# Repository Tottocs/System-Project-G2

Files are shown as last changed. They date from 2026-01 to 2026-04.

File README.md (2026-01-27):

# Description

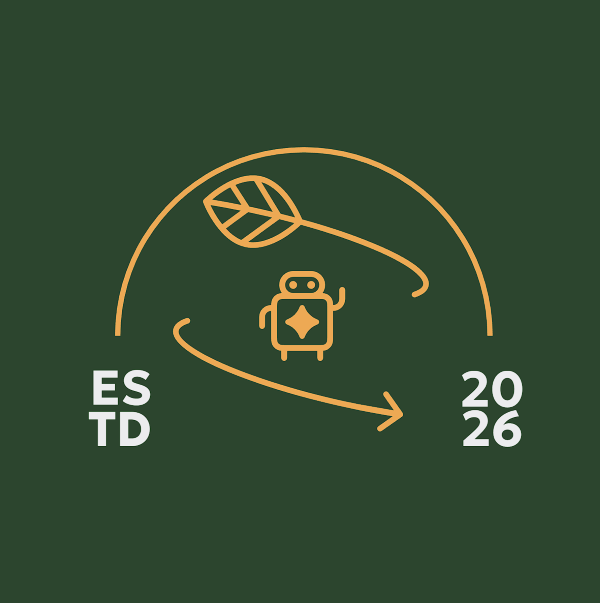
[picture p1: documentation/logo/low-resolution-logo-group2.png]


Recycling robot that collects rubbish and places it in designated areas.  
Includes code and CAD models with documentation.

## The Team

> - Abdalrahman Al-Zandi
>>Managing Director  
>>Mechanical Engineer
> - Torin Stanton-Andersson
>>Digital Systems Engineer  
>>Electronic and Wiring Engineer
> - David Mariani
>>Workshop Engineer  
>>Electronics and Wiring Engineer  
> - Aidan Johnstone
>>Software Engineer  
>>Personal Relations  
> - Lucy Grierson
>>Company Secretary  
>>Software Engineer  
> - Ben Albeson
>>Web Designer  
>>Digital Systems Engineer  

## Naming Convention For Files  

Lowercase and hyphen with group2 at end:  
***name-name-group2.c*** // Example of c file

Exception is when document is not created by the team.  
Then group2 is not used.

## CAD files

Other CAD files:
mechanical/base-group2.iam
mechanical/base/buggy-body-assembly-ready-group2.ipt
mechanical/base/rubbish-container-group2.ipt
mechanical/base/us-sensor-mount.ipt
mechanical/battery-model-group2.ipt
mechanical/buggy-body-group2.ipt
mechanical/buggy-group2.iam
mechanical/buggy/battery-model-two-group2.ipt
mechanical/buggy/buggy-topside-group2.ipt
mechanical/buggy/line-follower-group2.ipt
mechanical/buggy/motor-group2.ipt
mechanical/buggy/nub-group2.ipt
mechanical/buggy/nut-group2.ipt
mechanical/buggy/wheel-group2.ipt
mechanical/crane-base-assembly.iam
mechanical/crane/horozontal-arm-comp-group2.ipt
mechanical/crane/rotating-base-bottom-group2.ipt
mechanical/crane/rotating-base-head-group2.ipt
mechanical/crane/spool-group2.ipt
mechanical/door-assembly-group2.iam
mechanical/door/door-group2.ipt
mechanical/door/door-pinion-group2.ipt
mechanical/door/door-rail-group2.ipt
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

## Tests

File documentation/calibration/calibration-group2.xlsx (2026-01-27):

100 | 1 | 2 | 3 | Init left spd | Total |  |  | Testing straight
Min Blinks | 8 | 10 | 10 | 80 | 126.6666667 | 126.6666667% |  | First two sec | After
Max Blinks | 10 | 11 | 11 | 80 | 133.3333333 | 133.3333333% | 126 vs 100 | right | straight
 |  |  |  |  |  |  | 190 vs 150 | right | straight
150 | 1 | 2 | 3 | Init left spd | Total | Percent | 233 vs 200 | slight right | slight left
Min Blinks | 13 | 13 | 13 | 130 | 190 | 126.6666667%
Max Blinks | 14 | 15 | 15 | 130 | 203.3333333 | 135.5555556% | Battery at 3 bars
200 | 1 | 2 | 3 | Init left spd | Total
Min Blinks | 14 | 14 | 13 | 170 | 233.3333333 | 116.6666667%
Max Blinks | 15 | 15 | 15 | 170 | 245 | 122.5%

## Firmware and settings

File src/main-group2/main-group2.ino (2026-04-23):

#ifndef FIRMWARE_VERSION
#define FIRMWARE_VERSION "v.0.6" //Implementation of line following
#endif

/*
Authors: Lucy Grierson, Torin Stanton-Andersson, Ben Albeson

[] Ultrasonic Sensor
[x] RGB Sensor
[x] Motors
[x] Servos (Which ones)
[x] IR sensors
[x] Status LEDs
[x] Buzzer

Optional:
[] Eyes

*/


//Including project libraries
#include "include/ultrasonic-sensor-group2.h"
#include "include/ir-sensor-group2.h"
#include "include/motor-group2.h"
#include "include/rgb-sensor-group2.h"
#include "include/door-group2.h"

//Including online libraries
#include <Servo.h>

//UART only needed for debugging and or comunication between chips. Will slow the arduino computation
#define SERIAL_STATUS true // set false for field operation
#define UART_BAUDRATE 9600 //might need to be changed

// PINS
//---------------------------------
//Servo pins
#define DOOR_PIN 9

//Motor pins
#define MOT_A1_PIN 5 // IN2
#define MOT_A2_PIN 6 // IN1
#define MOT_B1_PIN 11 // IN3
#define MOT_B2_PIN 3 // IN4
#define CR_STATE_PIN 12
#define BUZZ_PIN 3
#define MAGNET_PIN A2
//Peripheral 
#define BUTTON 7

//Debug LEDs
#define ERROR_LED 4
#define CALIBRATION_LED 8
#define RUNNING_LED 13

int IR_Sensor_Pins[3] = {A3,A2,A1};
int positions[4] = {20, 80, 130, 170};// [0]=pickup, [1-3]=bins
#define CRANE_SERVO_PIN 10 // change to free pin

// CONSTANTS
//------------------------------------
#define MAGNET_ON 1023
#define MAGNET_OFF 0
//MAX and MIN distances for detectable object (cm)
#define MIN_DIST 1 //Needs to be changed
#define MAX_DIST 20 //Needs to be changed

//Number of rubiish objects to pick up
#define N_OBJECTS 3

#define DOOR_OPEN_STATE 1
#define DOOR_CLOSED_STATE 0

//Delays in ms
#define START_DELAY 1000
#define DRV_OFF_BLK_DEL 500
#define BASE_DELAY 700
#define DROPOFF_DELAY 1500
#define OBSTACLE_DELAY 2000
#define BLK_CONFIRM_DELAY 50
#define TURN_DELAY 700
#define CRANE_MOVE_DELAY 1000
#define MAGNET_MOVE_DELAY 1000

//Timout
#define BLK_LINE_TIMEOUT 500UL 
#define BLINK_LENGTH 500

//Buzzer
#define BUZZ_FREQ 3000
#define BUZZ_DURATION 500
#define BEEP_PAUSE_TIME 300
#define NUM_BEEPS 2

//Refresh rate of entire programme in ms
#define REFRESH_RATE 50

//Speeds
#define NOMINAL_SPD 120
#define STARTING_SPD 80
#define DROPOFF_SPD 80
#define OBSTACLE_SPD 80
#define LINE_CAL_SPD 100
#define TURN_SPD 100
#define HOME_SPD 80
 
//Distances in cm
#define DIST_TO_DROPOFF 5

//Line following
#define ALL_BLACK B111
#define NO_BLACK B000

#define LM_CORRECTION 100 // Left motor correction

// OBJECTS
// --------------------------------------
Servo door;
Servo CraneServo;

RgbSensor rgbSensor;

// VARIABLES
//---------------------------------------

//90 degree turn checker
bool turned90 = false;

//130 degree turn checker
bool tunred130 = false;

//180 degree turn checker
bool turned180 = false;

//Motor speed variables
int LeftMotorSpeed = 0;
int RightMotorSpeed = 0;

//US sensor variables
unsigned long DistanceFront; //front sensor 
unsigned long DistanceRight; //side sensor
unsigned long DistanceBack; //back sensor

//IR Sensor variable
volatile int IR_Sensor_Status = B000;

//pickup and dropoff
int pickup = 0;
int dropoff = 0;

//
int visitedBins = 0;

//state 3
int dropOff = 0;

int ObjectDetected = 0;

char ObjectColour = 0;

char GetBinFromColor() { 
  ObjectColour = rgbSensor.detectDominantColor();
  const char R = 1;
  const char G = 2;
  const char B = 3;
  switch(ObjectColour) {
    case R:   return 1; // bin 1
    case G:   return 2; // bin 2
    case B:   return 3; // bin 3
    default:    return 1; // default bin (safe fallback)
  }
}

//states
enum RobotState {
  ERROR = 0,
  STARTING = 1,
  FOLLOW_LINE = 2,
  DROPOFF = 3,
  PICKUP = 4,
  HOME = 5,
  OBSTACLE = 6,
  FINISHED = 7
};

RobotState CurrentState = STARTING;

int startStage = 0;
int obstacleStage = 0;
int HomeState = 1;
bool HomeTurned = false;


void setup() {
  //setup serial
  #if SERIAL_STATUS == true 
  Serial.begin(UART_BAUDRATE); //Only used for debugging
  #endif
  //Button for calibration
  pinMode(BUTTON, INPUT_PULLUP);

  //Debug LEDs
  pinMode(ERROR_LED, OUTPUT);
  pinMode(CALIBRATION_LED, OUTPUT);
  pinMode(RUNNING_LED, OUTPUT);
  digitalWrite(RUNNING_LED, HIGH);
  
  //Servo setup
  door.attach(DOOR_PIN);
  CraneServo.attach(CRANE_SERVO_PIN);
  moveToPosition(0); // default pos

  //Crane
  pinMode(CR_STATE_PIN, OUTPUT);
   
  //Setup up ir sensor pins
  if (!Setup_IR_Sensors(IR_Sensor_Pins, BUTTON, CALIBRATION_LED)) {
    CurrentState = ERROR;
  } 
  digitalWrite(CALIBRATION_LED, LOW);

  //Setup main motor pins
  Setup_Main_Motors(MOT_A1_PIN, MOT_A2_PIN, 
                    MOT_B1_PIN, MOT_B2_PIN);

  //Setup rgb sensor
  rgbSensor.begin();
  //Set_Motor_Currents(NOMINAL_SPD, NOMINAL_SPD);
  //delay(3000); 


}

void loop() {
  //Serial.println(CurrentState);

  
  if (CurrentState != ERROR) { // Testing
     //CurrentState = STARTING;  
  }
  
  IR_Sensor_Status = Scan();
  switch(CurrentState)
  {

    case STARTING:
      Starting();   break;

    case FOLLOW_LINE:
      FollowLine(); break;

    case DROPOFF:
      Dropoff();    break;

    case PICKUP:
      Pickup();     break;

    case HOME:
      Home();       break;

    case OBSTACLE:
      Obstacle();   break;

    case ERROR:
      Error();      break;

    default:
      CurrentState = ERROR;
  }
  //delay(REFRESH_RATE); //might get rid
  
}

// State functions
// -------------------------------------------------

//STATE 1 go from charging point to line  
void Starting()
{
  switch(startStage)
  {
    // STEP 0
    case 0:
      Set_Motor_Currents(STARTING_SPD,STARTING_SPD);
      delay(BASE_DELAY);
      startStage = 1;
      break;
    case 1:

      Update_Direction(&LeftMotorSpeed,&RightMotorSpeed);
      Set_Motor_Currents(LeftMotorSpeed,RightMotorSpeed);
      if(IR_Sensor_Status == B111)
      { 
        Set_Motor_Currents(STARTING_SPD,STARTING_SPD);
        delay(BASE_DELAY);
        startStage = 2;
      }
      break;

    // STEP 2 turn right 
     case 2:
      Set_Motor_Currents(0,0);
      Turn_90_Clockwise();
      startStage = 0;
      CurrentState = FOLLOW_LINE;
      break;
    
    default:
      CurrentState = ERROR;
  }
}


//STATE 2 line following and pickup
void FollowLine()
{
  if(DistanceFront > MIN_DIST && DistanceFront < MAX_DIST)
  {
    CurrentState = OBSTACLE;
    return;
  }

  Update_Direction(&LeftMotorSpeed,&RightMotorSpeed);
  Set_Motor_Currents(LeftMotorSpeed,RightMotorSpeed);
  if (IR_Sensor_Status == ALL_BLACK) {
    Set_Motor_Currents(0,0);
    delay(BLK_CONFIRM_DELAY);
    Calibrate_On_Line(BLK_LINE_TIMEOUT);
  }

  if(ObjectDetected)
  {
    //PickupObject();
    //pickup code here or call helper ^
    pickup++;
  }

  if(pickup >= N_OBJECTS)
  {
    CurrentState = DROPOFF;
  }

}


//STATE 3 drop off 

void Dropoff()
{
  dropoff = 0;
  switch(dropoff)
  {
    // Detect drop-off area and move slightly forward
    case 0:
      if((IR_Sensor_Status == ALL_BLACK) && 
         (DistanceRight > MIN_DIST && DistanceRight < MAX_DIST))
      {
        Set_Motor_Currents(DROPOFF_SPD, DROPOFF_SPD);
        delay(DROPOFF_DELAY);

        Set_Motor_Currents(0, 0);
        dropoff = 1;
      }
      break;

    // Turn so the back faces the bin
    case 1:
      Turn_90_Anti_Clockwise();
      dropoff = 2;
      break;

    // Reverse until rear sensor detects bin
    case 2:
      Set_Motor_Currents(-NOMINAL_SPD, -NOMINAL_SPD);

      if (DistanceBack <= DIST_TO_DROPOFF)  // bin detected
      {
        Set_Motor_Currents(0, 0);
        dropoff = 3;

      }
      break;

    // Drop objects
    case 3:
      setDropoff(door, DOOR_OPEN_STATE);   // OPEN DOOR
      delay(500);      // allow servo to move
      dropoff = 4;
      break;

    // Move forward away from bin
    case 4:
      Set_Motor_Currents(NOMINAL_SPD, NOMINAL_SPD);
      delay(300);
      dropoff = 5;
      break;

    // Close door + return to line following
    case 5:
      setDropoff(door, DOOR_CLOSED_STATE);   // CLOSE DOOR

      Update_Direction(&LeftMotorSpeed, &RightMotorSpeed);
      Set_Motor_Currents(LeftMotorSpeed, RightMotorSpeed);

      if(IR_Sensor_Status != NO_BLACK)
      {
        dropoff = 0;
        CurrentState = FOLLOW_LINE;
      }
      break;
  }
}

void Pickup() {

  Set_Motor_Currents(0,0); // stop robot

  //go to pickup position
  moveToPosition(0);
  delay(CRANE_MOVE_DELAY);
  
  //input detect colour
  
  digitalWrite(CR_STATE_PIN, HIGH);//lower magnet
  delay(MAGNET_MOVE_DELAY);

  //activate electromagnet
  analogWrite(MAGNET_PIN, MAGNET_ON);
  delay(500);

  //lift object
  digitalWrite(CR_STATE_PIN, LOW);
  delay(MAGNET_MOVE_DELAY);

  //choose bin
  char binIndex = GetBinFromColor();

  //rotate to bin
  moveToPosition(binIndex);
  delay(800);

  //release object
  analogWrite(MAGNET_PIN, MAGNET_OFF);
  delay(500);

  //return to pickup position
  moveToPosition(0);

  pickup++;
  ObjectDetected = 0;

  CurrentState = FOLLOW_LINE;


}

//STATE 4 go home
void Home()
{
  const int Follow_Line = 1;
  const int Turning = 2;
  const int End = 3;
  
  //HomeState = End;
  switch (HomeState) {
  
  case Follow_Line:
    Update_Direction(&LeftMotorSpeed, &RightMotorSpeed);
    Set_Motor_Currents(LeftMotorSpeed, RightMotorSpeed);
    //if buggy has reached line turn onto line and stop at base line
    if(IR_Sensor_Status == ALL_BLACK)
    {
      Set_Motor_Currents(0,0);
      delay(BLK_CONFIRM_DELAY);
      Calibrate_On_Line(BLK_LINE_TIMEOUT);
      Set_Motor_Currents(NOMINAL_SPD*LM_CORRECTION/100,NOMINAL_SPD);
      delay(TURN_DELAY);
      HomeState = Turning;
    }
    break;
  
  case Turning:
    //Turn right
    Set_Motor_Currents(TURN_SPD*LM_CORRECTION/100,-TURN_SPD);
    if (IR_Sensor_Status == B001) {
      HomeState = Follow_Line;
      if (HomeTurned) {
        Set_Motor_Currents(TURN_SPD*LM_CORRECTION/100,-TURN_SPD);
        if (IR_Sensor_Status == B001) {
          HomeState = End;
        }
      }
      HomeTurned = true;
    }
    break;

  case End:
    Update_Direction(&LeftMotorSpeed, &RightMotorSpeed);
    Set_Motor_Currents(-RightMotorSpeed, -LeftMotorSpeed);
    if (IR_Sensor_Status == ALL_BLACK) {
      Set_Motor_Currents(0,0);
      exit(0); // stop forever until reset or power cycled
    }
    break;

  default: 
    CurrentState = ERROR;
  }
}


//STATE 5 avoid obstacle
void Obstacle()
{

  switch(obstacleStage)
  {

    //obstacle detected
    case 0:

      if(DistanceFront > MIN_DIST && DistanceFront < MAX_DIST)
      {
        Set_Motor_Currents(0,0);
        Beep(NUM_BEEPS); 
        delay(OBSTACLE_DELAY);
        Beep(NUM_BEEPS);
        Set_Motor_Currents(-OBSTACLE_SPD,-OBSTACLE_SPD);
        delay(OBSTACLE_DELAY);

        Turn_90_Anti_Clockwise(); // face alongside object
        obstacleStage = 1;
      }

      break;

    //following side of obstacle
    case 1:

      //wall following
      //if obstacle within range
      if(DistanceRight > 8 && DistanceRight < 12) //Maybe use abs()<<<<<<<<<<<<<<<<<<<<<
      {
        Set_Motor_Currents(50,50);
      }
      else if(DistanceRight < 8) //turn left too close
      {
        Set_Motor_Currents(50,80);
      }
      else if(DistanceRight > 12 && DistanceRight < 20) //turn right too far
      {
        Set_Motor_Currents(80,50);
      }
      else if(DistanceRight > MAX_DIST)//no obstacle detected go back to line following
      {
        Turn_90_Clockwise();
        obstacleStage = 2;
      }
      break;

    //go back to line following
    case 2:

      //ignore ultrasonic sensors
      Update_Direction(&LeftMotorSpeed,&RightMotorSpeed);
      Set_Motor_Currents(LeftMotorSpeed,RightMotorSpeed);

      //if line is detected go abck to pickup state
      if(IR_Sensor_Status != NO_BLACK)
      {
        obstacleStage = 0; // reset
        CurrentState = FOLLOW_LINE;
      }

      break;
  }
}

void Error() {
  Set_Motor_Currents(0,0);
  digitalWrite(RUNNING_LED, LOW);
  digitalWrite(CALIBRATION_LED, LOW);
  Blink(ERROR_LED, BLINK_LENGTH);
  //Serial.print("Error");
}

// Supplementary functions
// --------------------------------------------------------

void Beep(int BeepNumber) {
  int i = 0;
  while (i < BeepNumber) {
    tone(BUZZ_PIN, BUZZ_FREQ, BUZZ_DURATION);
    i++;
    delay(BEEP_PAUSE_TIME);
  }
}

void Blink(int LED_Pin, unsigned long BlinkLength) {
  digitalWrite(LED_Pin, HIGH);
  delay(BlinkLength),
  digitalWrite(LED_Pin, LOW);
  delay(BlinkLength);
}

void Calibrate_On_Line(unsigned long Timeout)  {
  unsigned long t0 = millis();
  unsigned long t1 = millis()+1;
  while (t1-t0 <= Timeout) {
    IR_Sensor_Status = Scan();
    if (IR_Sensor_Status == ALL_BLACK) {
      Set_Motor_Currents(0,0);
      return;
    }
    t1 = millis();
    Set_Motor_Currents(-LINE_CAL_SPD,-LINE_CAL_SPD);
  }
  Set_Motor_Currents(0,0);  
}

void moveToPosition(int posIndex) {
  if (posIndex < 0 || posIndex > N_OBJECTS) return;

  int target = positions[posIndex];
  int currentAngle = CraneServo.read();

  if (currentAngle < target) {
    for (int angle = currentAngle; angle <= target; angle++) {
      CraneServo.write(angle);
      delay(10);
    }
  } else {
    for (int angle = currentAngle; angle >= target; angle--) {
      CraneServo.write(angle);
      delay(10);
    }
  }
}

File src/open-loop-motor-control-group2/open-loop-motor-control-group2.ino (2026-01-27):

//C code on Arduino UNO

#define FIRMWARE_VERSION "v.1.0"

#define UART_BAUDRATE 9600 //At which speed the information is sent through the Arduino

#define LED_PIN 7 //Pin on the arduino board where the 

#define MOT_L1_PIN 5  //Connected to IN2 pin to the servos 
#define MOT_L2_PIN 6  //Connected to IN1 pin to the servos 
#define MOT_R1_PIN 9  //Connected to IN3 pin to the servos 
#define MOT_R2_PIN 10 //Connected to IN4 pin to the servos 
#define UPDATE_PERIOD 1500 // The servo speed updates every 1500 milliseconds + BLINK_DURATION
#define BLINK_PERIOD 100 //Blinks for 100 milliseconds after each updated 
int InitialLeftServoPWM = 80; //The initial pwm value that will increase to match the right pwm
const int ConstantRightServoPWM = 100; // Three chosen constant values of either 100 ,150 and 200
        // This can be changed to the right or left servo depending on which is lagging behind 

void setup(){
  //initiate
  Serial.begin(UART_BAUDRATE);
  
  //H-Bridge switches pins to output
  pinMode(MOT_L1_PIN, OUTPUT);
  pinMode(MOT_L2_PIN, OUTPUT);
  pinMode(MOT_R1_PIN, OUTPUT);
  pinMode(MOT_R2_PIN, OUTPUT);
  // The pins are set to low, indicating them being off
  digitalWrite(MOT_L1_PIN, LOW);
  digitalWrite(MOT_L2_PIN, LOW);
  digitalWrite(MOT_R1_PIN, LOW);
  digitalWrite(MOT_R2_PIN, LOW);
  //Setting LED pin to output
  pinMode(LED_PIN, OUTPUT);
}

void Set_Motor_pwm(int pwm, int IN1_PIN, int IN2_PIN)
{
  if (pwm < 0) {  //reverse speeds
    analogWrite(IN1_PIN, -pwm); /*if the pwm signal is negative, 
                              the signal gets sent through pin IN1 instead of pin IN2 */
    digitalWrite(IN2_PIN, LOW);

  } else { // stop or forward
    digitalWrite(IN1_PIN, LOW);
    analogWrite(IN2_PIN, pwm);
  }
}
//Inputs pwm for right and left and sets speed
void Set_Motor_Currents(int pwm_L, int pwm_R)
{
  Set_Motor_pwm(pwm_L, MOT_L1_PIN, MOT_L2_PIN);
  Set_Motor_pwm(pwm_R, MOT_R1_PIN, MOT_R2_PIN);

  //Prints status message to the console.
  Serial.print("Set motor R PWM = ");
  Serial.print(pwm_L);
  Serial.print(" motor R PWM = ");
  Serial.println(pwm_R);
}
//Drives forward and changes left servo speed every 1500 millieconds with a 100 millisecond blink
void Forward_Lag_Check(int PWM_L, int PWM_R, int Duration, int BlinkDuration)
{
  for (int LeftVariablePWM=PWM_L;LeftVariablePWM<=255;LeftVariablePWM+=5)
  {
    digitalWrite(LED_PIN, HIGH); // The first blink will be at the initial value
    delay(BlinkDuration);
    digitalWrite(LED_PIN, LOW);
    Set_Motor_Currents(LeftVariablePWM, PWM_R);
    delay(Duration);    

  }
}

void loop()
{
  //Implementing function in loop
  Forward_Lag_Check(InitialLeftServoPWM,ConstantRightServoPWM,UPDATE_PERIOD,BLINK_PERIOD); // sets speed of motors to value entered above for 0.5 sec and keeps repeating
}

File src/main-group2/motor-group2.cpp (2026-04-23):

#ifndef FIRMWARE_VERSION
#define FIRMWARE_VERSION "v.0.2"
#endif
/*
Author: Torin Stanton-Andersson
*/

#include <Arduino.h>
#include "include/motor-group2.h"

#define MAIN_MOTORS_STATUS true 
#define SERIAL_STATUS false

//Correction for the left servo, taken from calibration
#define MOTOR_CORRECT_PERCENT 100 

//Macro for dealing with percentage
#define MULT_PERCENT(a,b) a*b/100

#define UPDATE_90_DELAY 1000 //Needs changing
#define UPDATE_130_DELAY 1600
#define UPDATE_180_DELAY 2400 //Needs changing
#define TURN_SPD 100

int _MOT_A1_PIN;
int _MOT_A2_PIN;
int _MOT_B1_PIN;
int _MOT_B2_PIN;

bool Initialisation = false;

int Corrected_pwm_A;

// Setup pins before running motors
void Setup_Main_Motors(
  int MOT_A1_PIN, int MOT_A2_PIN, 
  int MOT_B1_PIN, int MOT_B2_PIN) {

  _MOT_A1_PIN = MOT_A1_PIN;
  _MOT_A2_PIN = MOT_A2_PIN;
  _MOT_B1_PIN = MOT_B1_PIN;
  _MOT_B2_PIN = MOT_B2_PIN;
  pinMode(MOT_A1_PIN, OUTPUT);
  pinMode(MOT_A2_PIN, OUTPUT);
  pinMode(MOT_B1_PIN, OUTPUT);
  pinMode(MOT_B2_PIN, OUTPUT);
  Initialisation = true;
}

void Set_Motor_pwm(int pwm, int IN1_PIN, int IN2_PIN) {

  if ((MAIN_MOTORS_STATUS == true) && (Initialisation == false)) {
    #if SERIAL_STATUS == true
    Serial.print("Error: Motors not initialised");
    #endif
    return;
  }

  if (pwm < 0) {
    analogWrite(IN1_PIN, -pwm);
    digitalWrite(IN2_PIN, LOW);
  } else {
    digitalWrite(IN1_PIN, LOW);
    analogWrite(IN2_PIN, pwm);
  }
}

void Set_Motor_Currents(int pwm_A, int pwm_B) {
  Corrected_pwm_A = MULT_PERCENT(pwm_A, MOTOR_CORRECT_PERCENT);
  Set_Motor_pwm(Corrected_pwm_A, _MOT_A1_PIN, _MOT_A2_PIN);
  Set_Motor_pwm(pwm_B, _MOT_B1_PIN, _MOT_B2_PIN);
}

//90 degree anticlockwise turn helper
void Turn_90_Anti_Clockwise()
{
  //left forward right backward
  Set_Motor_Currents(-TURN_SPD, TURN_SPD);
  delay(UPDATE_90_DELAY); //might need adjusted

  Set_Motor_Currents(0,0);
}

//90 degree clockwise turn helper
void Turn_90_Clockwise()
{
  //right forward left backward
  Set_Motor_Currents(TURN_SPD, -TURN_SPD);
  delay(UPDATE_90_DELAY); //might need adjusted

  Set_Motor_Currents(0,0);
}

//130 degree clockwise turn helper
void Turn_130_Clockwise()
{
  //right forward left backward
  Set_Motor_Currents(TURN_SPD, -TURN_SPD);
  delay(UPDATE_130_DELAY); //might need adjusted

  Set_Motor_Currents(0,0);
}

//180 degree turn helper
void Turn_180()
{
  //left forward right backward
  Set_Motor_Currents(TURN_SPD, -TURN_SPD);
  delay(UPDATE_180_DELAY); //might need adjusted

  Set_Motor_Currents(0,0);
}

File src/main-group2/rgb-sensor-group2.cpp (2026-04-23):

#include "include/rgb-sensor-group2.h" 

#define SERIAL_STATUS false
#define R 1
#define G 2
#define B 3

RgbSensor::RgbSensor() 
  : tcs(TCS34725_INTEGRATIONTIME_614MS, TCS34725_GAIN_16X) {}

int RgbSensor::begin() {
    if (tcs.begin()) {
        #if SERIAL_STATUS == true 
        Serial.println("Found sensor");
        #endif
        return (1);
    } else {
        #if SERIAL_STATUS == true 
        Serial.println("No TCS34725 found ... check your connections");
        #endif
        return (0);
    }
}

void RgbSensor::readAverages(float &rAvg, float &gAvg, float &bAvg) {
    uint32_t rTotal = 0;
    uint32_t gTotal = 0;
    uint32_t bTotal = 0;

    for (int i = 0; i < SAMPLE_COUNT; i++) {
        uint16_t r, g, b, c;
        tcs.getRawData(&r, &g, &b, &c);

        rTotal += r;
        gTotal += g;
        bTotal += b;

        delay(SAMPLE_DELAY_MS);
    }

    rAvg = rTotal / (float)SAMPLE_COUNT;
    gAvg = gTotal / (float)SAMPLE_COUNT;
    bAvg = bTotal / (float)SAMPLE_COUNT;
}

char RgbSensor::detectDominantColor() {
    float rAvg, gAvg, bAvg;
    readAverages(rAvg, gAvg, bAvg);
    float r_scaled = rAvg * R_SCALING_FACTOR;
    float g_scaled = gAvg * G_SCALING_FACTOR;
    float b_scaled = bAvg * B_SCALING_FACTOR;
    if ((r_scaled > g_scaled * THRESHOLD_FACTOR) && (r_scaled > b_scaled * THRESHOLD_FACTOR)) {
        return R;
    } 
    else if ((g_scaled > r_scaled * THRESHOLD_FACTOR) && (g_scaled > b_scaled * THRESHOLD_FACTOR)) {
        return G;
    } 
    else if ((b_scaled > r_scaled * THRESHOLD_FACTOR) && (b_scaled > g_scaled * THRESHOLD_FACTOR)) {
        return B;
    }

    return 0;
}
/*
void RgbSensor::update() {
    float rAvg, gAvg, bAvg;
    readAverages(rAvg, gAvg, bAvg);

    float r_scaled = rAvg * R_SCALING_FACTOR;
    float g_scaled = gAvg * G_SCALING_FACTOR;
    float b_scaled = bAvg * B_SCALING_FACTOR;

    char dominantColor = detectDominantColor();

    #if SERIAL_STATUS == true
    Serial.print("Scaled -> ");
    Serial.print("R="); Serial.print(r_scaled);
    Serial.print(" G="); Serial.print(g_scaled);
    Serial.print(" B="); Serial.print(b_scaled);

    Serial.print(" | Dominant: ");
    Serial.println(dominantColor);
    #endif

    delay(LOOP_DELAY_MS);
}
*/

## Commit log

2026-01-24 Added Datasheets
    Component datasheets for ultrasound sensor and IR sensor
2026-01-24 Create calibration-group2.xlsx
    Includes calibration details for motors
    [calibration-group2.xlsx]
2026-01-26 Added motor code
    Calibration and test code
2026-01-26 Add files via upload
    Servo datasheet
2026-01-27 Create ultrasonic-sensor-group2.ino
    Initial commit of ultrasonic sensor
2026-01-29 Create state-diagram-group2.drawio
    Flowchart of the robot's states
2026-02-03 Create electrical-architecture-group2.drawio
    Initial schematic of entire electrical architecture
2026-02-14 Update ultrasonic-sensor-group2.ino
    Removed inconsistent type casting
2026-02-23 Create ultrasonic-sensor-group2.cpp
    Initial commit of us sensor code. Copied from one of Tottocs repositories.
2026-02-23 Create ultrasonic-sensor-group2.h
    Initial commit of header to go with us sensor code.
2026-02-23 Renamed and Moved files
    Flowchart and electrical architecture were affected.
2026-02-23 Update ultrasonic-sensor-group2.cpp
    Minor change
2026-02-23 Create rubbish-container-group2.ipt
    Initial draft of rubbish container
    [rubbish-container-group2.ipt]
2026-02-23 Create buggy-assembly-group2.iam
    Initial commit of assembly
    [buggy-assembly-group2.iam]
2026-02-24 Create ultrasonic-sensor-group2.ipt
    Initial sketch for ultrasonic sensor cad
    [ultrasonic-sensor-group2.ipt]
2026-02-24 Update ultrasonic-sensor-group2.ipt
    3D model for the ultrasonic sensor created
    [ultrasonic-sensor-group2.ipt]
2026-02-24 Create battery-model-group2.ipt
    Aidans battery model removed from container branch and added to this branch
    [battery-model-group2.ipt]
2026-02-24 Delete battery-model-group2.ipt
    Removed from this branch (and added to battery-cad)
    [battery-model-group2.ipt]
2026-02-25 Buggy body .ipt file
    Original rough sketch
    [Buggy_Body.ipt]
2026-02-25 Create initial-rubbish-group2.ipt
    Added test rubbish object
    [initial-rubbish-group2.ipt]
2026-02-25 Create ultrasonic-sensor-2-group2.ipt
    copy of us sensor due to other pc opened file
    [ultrasonic-sensor-2-group2.ipt]
2026-02-25 Added updated CAD files and full assembly
    [Buggy_Body_assembly_ready.ipt, buggy-assembly-group2.iam, crane-base-assembly.iam]
2026-02-26 Delete ultrasonic-sensor-group2.ipt
    Old version
    [ultrasonic-sensor-group2.ipt]
2026-02-26 Renamed us sensor cad
    [ultrasonic-sensor-group2.ipt]
2026-02-26 Added mount for the ultrasonic sensor
    [us-sensor-mount.ipt]
2026-02-26 Update crane-base-assembly.iam
    Fixed planes
    [crane-base-assembly.iam]
2026-02-26 Update Buggy_Body_assembly_ready.ipt
    Created pins connection to crane base
    [Buggy_Body_assembly_ready.ipt]
2026-02-26 Update buggy-assembly-group2.iam
    Constrained nearly everything apart from one axis on the rubbish container
    [buggy-assembly-group2.iam]
2026-02-26 Renamed Buggy Base
    [buggy-assembly-group2.iam, buggy-body-assembly-ready-group2.ipt]
2026-02-26 Rename BUGGY TOPSIDE.ipt to buggy-topside-group2.ipt
    [buggy-topside-group2.ipt]
2026-02-26 Rename line follower.ipt to line-follower-group2.ipt
    [line-follower-group2.ipt]
2026-02-26 Rename motor mount.ipt to motor-mount-group2.ipt
    [motor-mount-group2.ipt]
2026-02-26 Rename rotating base bottom.ipt to rotating-base-bottom-group2.ipt
    [rotating-base-bottom-group2.ipt]
2026-02-26 Rename rotating base head.ipt to rotating-base-head-group2.ipt
    [rotating-base-head-group2.ipt]
2026-02-26 Update crane-base-assembly.iam
    Updated links
    [crane-base-assembly.iam]
2026-02-26 Update Assembly
    Added a few parts to assembly
    [buggy-assembly-group2.iam, buggy-topside-group2.ipt]
2026-02-27 rubbish-container-walls
    added walls to hold the rubbish container
    [buggy-assembly-group2.iam, buggy-body-assembly-ready-group2.ipt]
2026-02-27 Delete mechanical/DoorAssembly.iam
    sucks bum
    [DoorAssembly.iam]
2026-02-27 Rename mechanical/buggy-body-group2.ipt to mechanical/unused/buggy-body-group2.ipt
    moved to unused folder
    [buggy-body-group2.ipt]
2026-02-27 Update battery-model-group2.ipt
    Fixed battery from inches
    [battery-model-group2.ipt]
2026-02-27 Renamed files
    [battery-model-two-group2.ipt, buggy-group2.iam, buggy-topside-group2.ipt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]
2026-02-27 Rename files
    [door-group2.ipt, door-pinion-group2.ipt, door-rail-group2.ipt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]
2026-02-27 Moved files
    [buggy-assembly-group2.iam, buggy-body-assembly-ready-group2.ipt, rubbish-container-group2.ipt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]
2026-02-27 Tidied up files
    [base-group2.iam, battery-model-group2.ipt, initial-rubbish-group2.ipt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]
2026-02-27 Fixed links to files
    [base-group2.iam, crane-base-assembly.iam, door-assembly-group2.iam]
2026-03-01 Added us sensor file
    Added header and c++ file
2026-03-04 Update and rename RGB code.ino to rgb-sensor-group2.ino
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2026-03-05 Update and rename src/rgb-sensor-group2.ino to src/rgb-sensor-group2/rgb-sensor-group2.ino
    added to its own folder
2026-03-05 Delete ir-sensor-group2
    Wrong file type
2026-03-05 Update ultrasonic-sensor-group2.cpp
    Edited FIRMWARE_VERSION not to update if the main file already has a version
2026-03-05 Created cpp files
    From ir-sensor code which Lucy added
2026-03-05 Update main-group2.ino
    Initial accommodation of IR sensor code
2026-03-05 Updating main-group2
    Second draft of implementing IR sensors and line following
2026-03-06 Update ir-sensor-group2.cpp
    Tidied up code, compile time ready
2026-03-06 Update motor-group2.cpp
    Tidied code and removed unused function. Compile ready.
2026-03-06 Update ultrasonic-sensor-group2.cpp
    Added recommendation
2026-03-06 Update ir-sensor-group2.h
    Minor correction
2026-03-06 Update ir-sensor-group2.cpp
    Corrections on previous commit and added serial status variable
2026-03-06 Update main-group2.ino
    Added setup for ir sensor pins
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2026-03-08 Update ultrasonic-sensor-group2.ipt
    Moved membranes and added oscillator
    [ultrasonic-sensor-group2.ipt]
2026-03-09 Remade US Sensor cad to specs
    [us-sensor-mount.ipt]
2026-03-09 Edited cad again to fix fitting
    [us-sensor-mount.ipt]
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2026-03-10 Update ir-sensor-group2.cpp
    Added working calibration for ir sensors
2026-03-10 Update ultrasonic-sensor-group2.h
    Added internal distance for each component
2026-03-10 Update ultrasonic-sensor-group2.cpp
    Reduced timeout to 5000ms and added internal distance for every us sensor
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2026-03-10 Update motor-group2.cpp
    Added motor speed correction
    [motor-group2.cpp]
2026-03-10 Update main-group2.ino
    Minor corrections
    [main-group2.ino]
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2026-03-23 Update main-group2.ino
    Added correction for motors. Does not work
    [main-group2.ino]
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2026-03-24 Update door code
    Corrected for servo
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2026-03-24 Update main-group2.ino
    Fixed some of the pickup code errors
    [main-group2.ino]
2026-03-24 Update motor-group2.cpp
    Corrected turning clockwise and anti clockwise
    [motor-group2.cpp]
2026-03-24 Update main-group2.ino
    Fixed starting
    [main-group2.ino]
